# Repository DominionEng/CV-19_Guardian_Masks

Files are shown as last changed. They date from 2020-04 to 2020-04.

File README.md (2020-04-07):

# Description

In response to shortages in NIOSH-approved PPE during the COVID-19 crisis, many individuals including healthcare professionals and first responders are turning to improvised masks for protection. To help provide for more controlled protection under these circumstances, Dominion Engineering, Inc. (DEI) has developed a custom adaptor that, along with commonly available materials, can be used to convert a standard snorkel mask into a reusable, full face respirator that effectively protects the eyes, nose and mouth from airborne particles.  We have coordinated independent testing to confirm that these converted masks pass a standard mask fit test and to assess the efficacy of commonly available filter insert materials.

To assist individuals who may lack access to approved PPE such as N95 respirators and face shields, DEI is publishing the CV-19 Guardian Respirator Adaptor design here, along with instructions for making a converted mask using this adaptor.  For additional technical information, including filter efficacy testing results for commonly available materials that can be used to make filter inserts for this adaptor, refer to the attached PDF file.

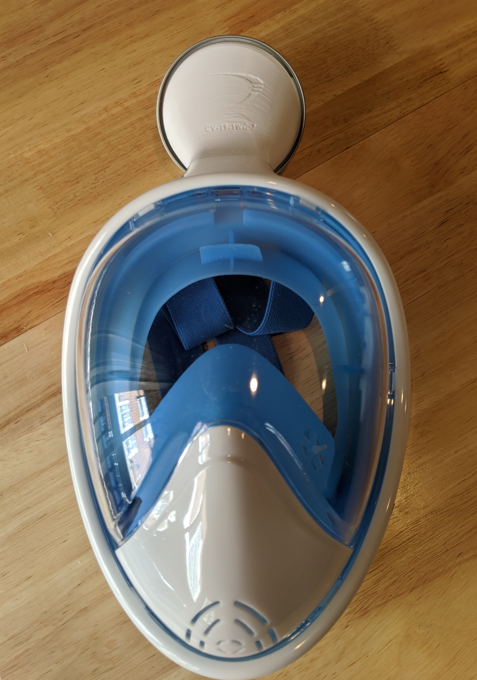
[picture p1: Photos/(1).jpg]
Mask with Adapter


**Disclaimer**: _Improvised devices of the type discussed herein are not NIOSH-approved and the user bears all liability associated with the use of such devices.  DEI is making this information available as a public service, but does not make any warranty, expressed or implied, that the use of the device described herein will protect a party from COVID-19 or any other airborne viruses._

**To assemble a converted respirator mask, you will need the following:**

1. 3D printed adaptor (design file attached)
2. Compatible snorkel mask
3. Filter insert material
4. Wide mouth lid (mason jar, or equivalent)

## Snorkel Mask

The CV-19 Guardian Respiratory Adaptor is designed to fit the [DIVELUX snorkel mask](https://www.amazon.com/dp/B072KDWVSV/ref=cm_sw_em_r_mt_dp_U_PJ5FEbJPZE8VG).  Many other commonly available snorkel masks utilize similar construction.  DEI will continue to evaluate the compatibility of other masks with the CV-19 Guardian Respirator Adaptor and publish additional compatibility information as it becomes available.

## Filter Insert

Once the CV-19 Guardian Respirator Adaptor is inserted into the compatible snorkel mask, a filter insert cut from a commonly available material that effectively captures airborne particles is placed on the sealing surface of the adaptor and secured in place using a compatible lid.  The attached PDF file provides instructions for properly making and using filter inserts, along with URL links for commonly available materials that provide effective protection against airborne particles.  One example material with good breathability and >99% filtration efficiency of airborne particles of interest is two layers of [ADO Pro Pac fabric](https://www.homedepot.com/p/ADO-Products-10-2-ft-x-375-ft-Pro-Pac-Insulation-Fabric-ICPP122/302709283), which is commonly used to capture particulate from blown insulation.

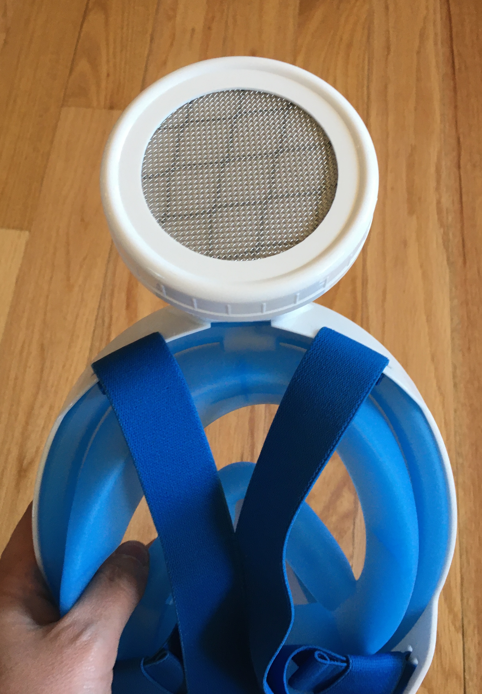
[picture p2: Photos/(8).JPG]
Filter Insert


As configured, most standard snorkel masks such as the DIVELUX mask allow the wearer breathe filtered air in through the CV-19 Guardian Respirator and filter insert, and exhale unfiltered air through a vent valve in the front of the mask.  This is equivalent to an N95 mask with an exhaust valve, which protects only the person wearing the mask, but not those in close proximity from any airborne particles expelled by the wearer.  Most full face coverage respirator masks utilize this type of construction because it is easier to breathe and prevents mask fogging and filter deterioration due to moisture.  However, if it is desirable for the mask to function in a similar manner to an N95 max without an exhaust valve, the vent valve in the snorkel mask can be effectively blocked by taping over it on the interior of the mask.  This makes it more difficult for the wearer to breathe through the mask, but ensures both inhaled and exhaled air are filtered (protecting both the wearer from surrounding airborne particles, as well as those in close proximity from any airborne particles expelled by the wearer).

## Wide Mouth Lid

For maximum compatibility and ease of use for the general public, the diameter and threading of the CV-19 Guardian Respirator Adaptor is the same as that of a wide mouth mason jar.  Any standard wide mouth mason jar lid ring (for canning) will fit the adaptor and function as intended (see photos).  Compatible lids with sprouting or straining inserts provide good structural protection for the filter insert.  One example lid of this type is the 
[Original Speed Strainer Lid® (wide mouth size)](https://www.unboundfarm.com/The-Original-Speed-Strainer-Lid®_p_12.html).

It is not recommended to cut a hole in a single-piece mason jar lid as the sharp edges could damage and compromise the integrity the filter insert.

## Details

For additional technical details, refer to the Photos and PDF file.

## 3D Print settings

* Printer used for prototyping: Prusa Mk3
* Rafts: No
* Supports: None
* Resolution: 0.2 mm
* Infill: 20%
* Filament: Hatchbox PLA, White

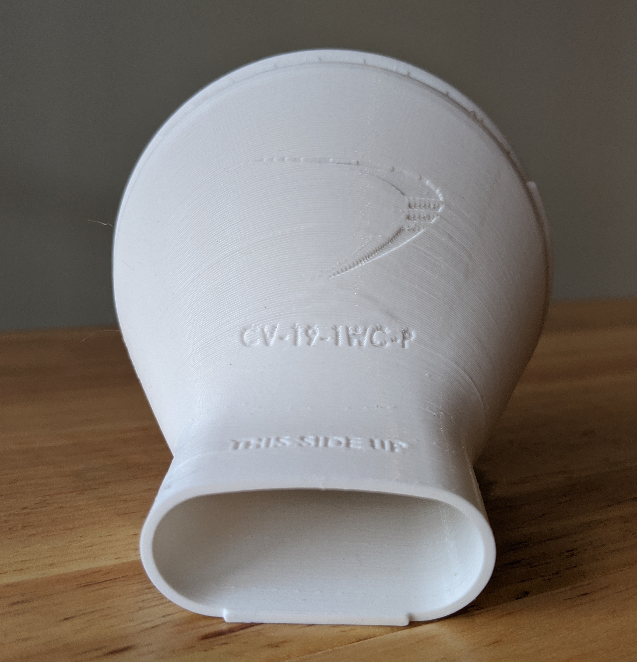
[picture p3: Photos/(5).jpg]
Adapter


## Material of construction and finishing options

* PETG or PLA are suitable.  In absence of these, other materials should be acceptable as well.
* ABS tends to shrink after production; a prototype made from this works acceptably, but the shrinkage could result in an inferior seal at the interface or require adjustment.
* PETG is chemically resistant, so it may be a good candidate if masks will be chemically decontaminated.
*  Multi-Jet Fusion (MJF) is expected to be an ideal process for commercial production of this part due to the durability of the resulting parts and demonstrated ability to withstand autoclave disinfection.

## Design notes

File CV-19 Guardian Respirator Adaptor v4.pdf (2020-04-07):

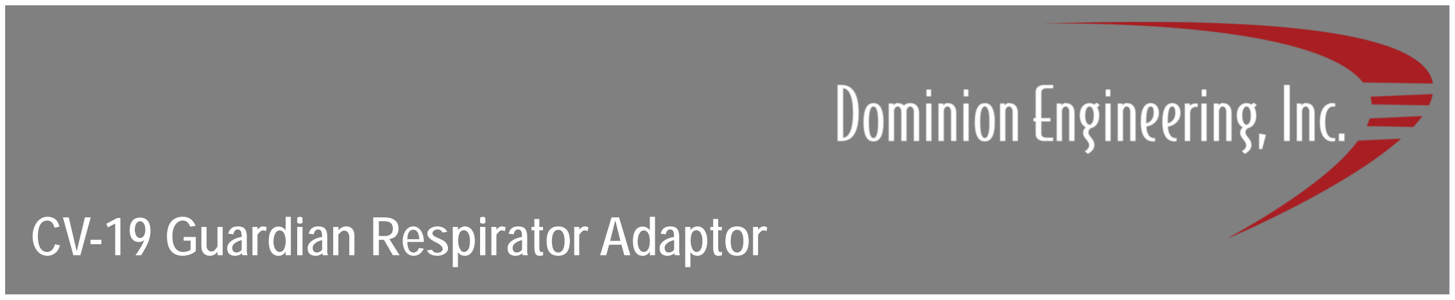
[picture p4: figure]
CV-19 Guardian Respirator Adaptor

Description
The CDC provides guidance for optimizing the supply of N95 respirators during the COVID-19 crisis (see Reference [1]). This includes crisis/alternate strategies such as the use of non-NIOSH approved masks when N95 respirators are no longer available. Along with compatible mask and filter insert, the CV-19 adaptor is designed to provide engineered protection in lieu of a homemade mask under these circumstances. To assist individuals who lack access to PPE, DEI has made this adaptor design freely available to the public and has separately published information regarding compatible masks and filter efficacy for commonly available materials (fabrics, HVAC filters, etc.). This device is not NIOSHapproved. User bears all liability associated with its use. DEI is making this information available as a public service, but does not make any warranty, expressed or implied, that the use of this device will protect a party from COVID-19 or any other airborne viruses.

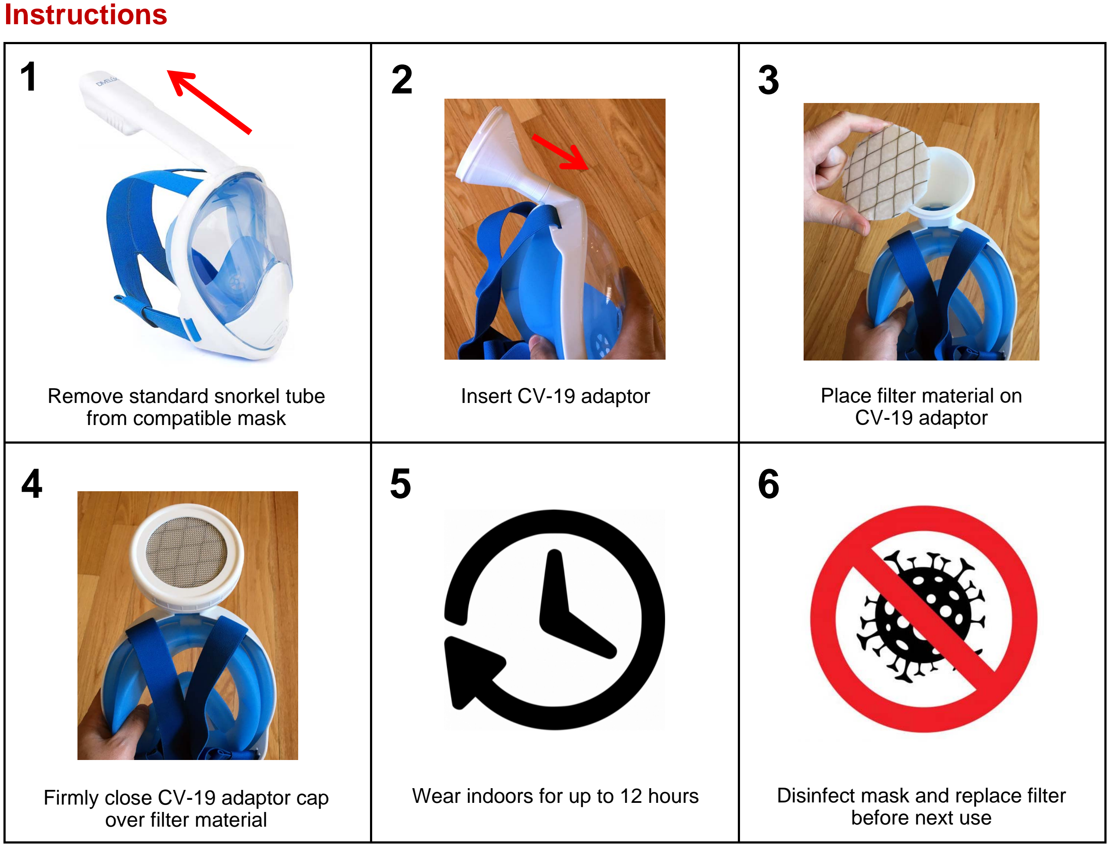
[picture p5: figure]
Instructions

1. https://www.cdc.gov/coronavirus/2019-ncov/hcp/respirators-strategy/crisis-alternate-strategies.html
1 Remove standard snorkel tube from compatible mask | 2 Insert CV-19 adaptor | 3 Place filter material on CV-19 adaptor
4 Firmly close CV-19 adaptor cap over filter material | 5 Wear indoors for up to 12 hours | 6 Disinfect mask and replace filter before next use

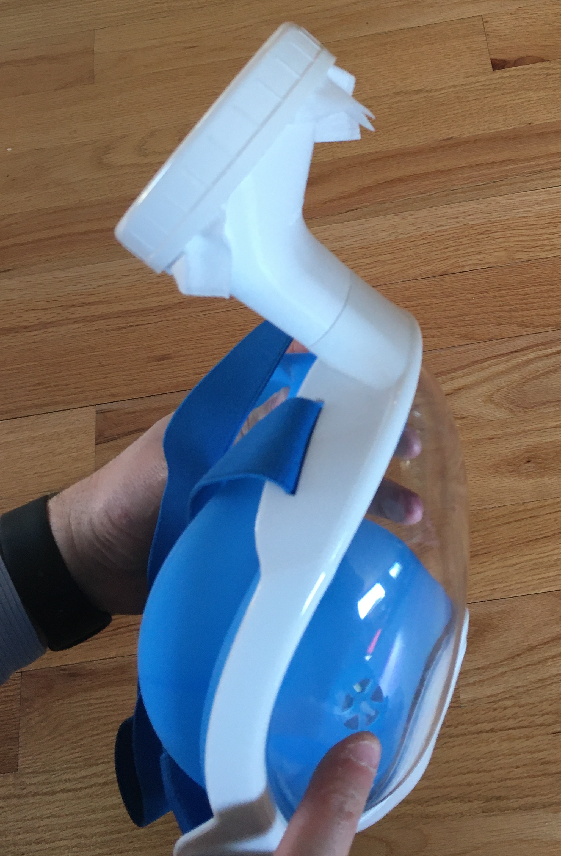
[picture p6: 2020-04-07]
Photos/(13)a.JPG

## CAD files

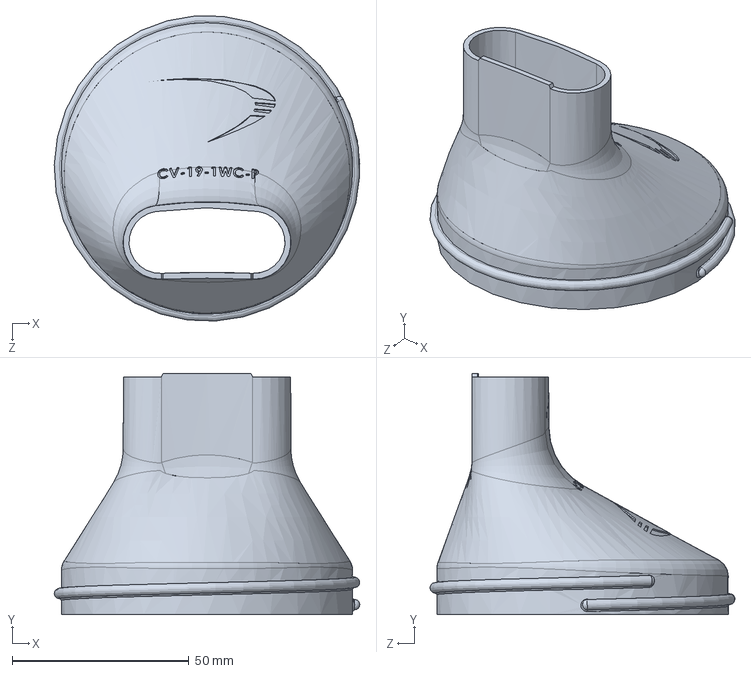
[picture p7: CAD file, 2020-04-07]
Solid Models/CV-19-1WC-P_V02.SLDPRT
86.6 x 68.3 x 86.4 mm

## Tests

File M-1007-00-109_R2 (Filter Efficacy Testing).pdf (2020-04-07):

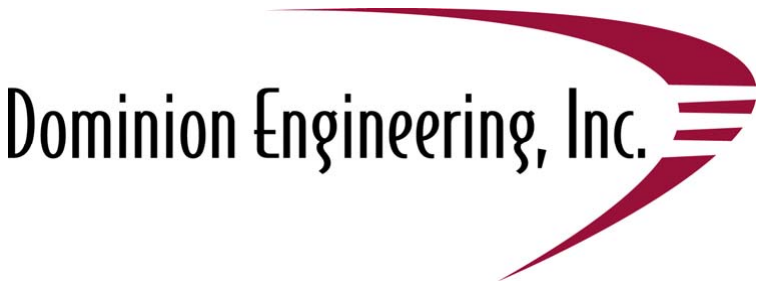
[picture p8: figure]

## MEMO

No.: | M-1007-00-109, Rev. 2
Date: | April 7, 2020
Subject: CV-19 Guardian Respirator Adaptor – Filter Insert Testing

### 1 Background

In response to the shortage of approved PPE such as N95 respirators and faceshields during the COVID-19 crisis, DEI developed the CV-19 Guardian Respirator Adaptor that, along with commonly available materials, can be used to convert a standard snorkel mask into a reusable, full face respirator that effectively protects the eyes, nose and mouth from airborne particles. In an emergency, commonly available materials such as HVAC filters and fabrics/netting for blown insulation can be cut into consumable filter inserts for use with the CV-19 Guardian Respirator Adaptor and a compatible mask as shown in Figure 1 and Figure 2.

DEI conducted testing to evaluate the efficacy of various materials that are readily available and can be used to make these filter inserts. This testing is summarized below.

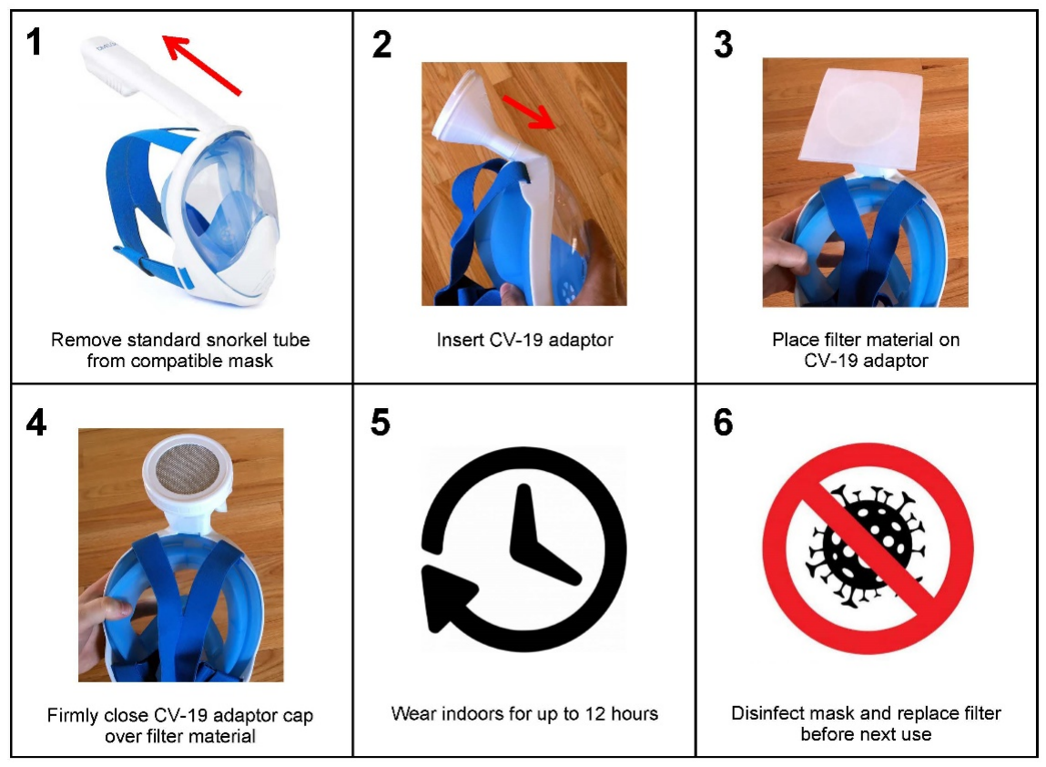
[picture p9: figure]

Figure 1 Use of Flexible Filter Insert in CV-19 Guardian Respirator Adaptor (ex., 2 layers of ADO Pro Pac insulation fabric)

M-1007-00-109, Rev. 2
p. 2 of 3

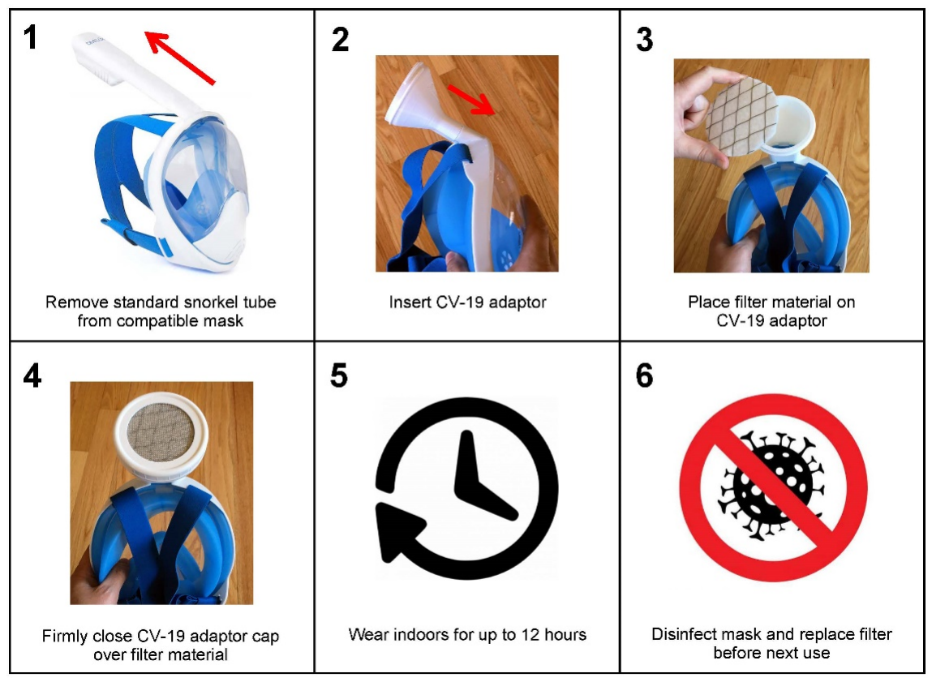
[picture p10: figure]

Figure 2 Use of Rigid Filter Insert in CV-19 Guardian Respirator Adaptor (ex., Aprilaire 213 furnace filter with rigid metal backing)

### 2 Filter Efficacy Testing

A converted respirator mask assembled using a DIVELUX mask, a CV-19 Guardian Respirator Adaptor and filter insert were subjected to and successfully passed a standard mask fit test using a PortaCount 8038 testing system as shown in Figure 3.

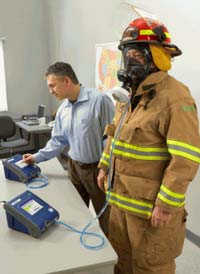
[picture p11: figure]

Figure 3 Respirator Fit Testing Using PortaCount 8038

M-1007-00-109, Rev. 2
p. 3 of 3
This testing system was also used to test the filtration efficiency of a number of readily available materials that could be used to make consumable filter inserts for the CV-19 Guardian Respirator Adaptor. In these tests, airborne particles were passed through candidate filter inserts and the particle concentration was measured before and after passing through the filter insert. Test results are summarized in Table 1.

As summarized in this table, a number of commonly available materials were found to capture >99% of airborne particles of interest*
with good breathability. When paired with a suitably tight fitting mask, filter inserts made from these materials provide a level of protection equivalent to or exceeding that of an N95 respirator (>95% capture, including leakage). In testing presented herein, a DIVELUX snorkel mask fitted with a CV-19 Guardian Respirator Adaptor and such filter inserts met the filtration performance requirements for an N95 respirator under typical fit testing activities (talking, moving head, bending over, etc.).

When making and installing filter inserts from flexible material such as the ADO Pro Pac insulation fabric, it is recommended that the chosen material be cut into squares at least 4.5 x 4.5 inches in size (see Figure 1). This ensures that the filter insert completely covers the sealing face of the adaptor and is held in place between the threads of the adaptor and lid. The four corners of the square should stick out past the lid after assembly in equal amounts, indicating that the full sealing face of the adapter is covered with material. Use of flexible sheet material as described above is the recommended approach in most cases, as it requires the least precision and is easily done without special tools.

When making and installing filter inserts from rigid material such as the Aprilair 213 furnace filter which has a robust metal backing, the filter insert must be cut into a circle with a diameter of 3.40 inches and pressed into the lid with the metal grid oriented away from the adaptor (see Figure 2). This ensures that the filter media seals properly against the adaptor, and that the filter insert is reliably positioned.

*
The test equipment used counts particles that are in the 0.02 to 1.0 micron size range.

M-1007-00-109, Rev. 2
p. 4 of 3
Table 1 | Filtration Efficiency of Commonly Available Materials
Description | Ambient Particulate | Filtered Particulate | Filter Efficiency (% Capture) | Recommended as Filter Insert? | Comments & Product URL
ADO Pro Pac Insulation Fabric (2 layers) | 801 | 5 | 99.4% | Yes | Excellent filtration, good breathability, readily available in large quantities, easy to work with
https://www.homedepot.com/p/ADO-Products-10-2-ft-x-375-ft-Pro-Pac-Insulation-Fabric-ICPP122/302709283
ADO Pro Pac Insulation Fabric (1 layer) | 807 | 39 | 95.2% | Yes (2 layers) | Acceptable, but recommend using 2 layers for improved filtration https://www.homedepot.com/p/ADO-Products-10-2-ft-x-375-ft-Pro-Pac-Insulation-Fabric- ICPP122/302709283
Aprilaire 213 Furnace Filter | 102 | 0.01 | 100.0% | Yes | Excellent filtration, good breathability, includes helpful metal reinforcement https://www.amazon.com/dp/B00R3G53NI/ref=cm_sw_em_r_mt_dp_U_NwcGEb2XZH3ZD
Filtrete 1000 Alergen Defense AC Filter | 100 | 0.1 | 99.9% | Yes | Excellent filtration, good breathability, but small pleats and metal grids are hard to work with https://www.amazon.com/dp/B004Q69HIU/ref=cm_sw_em_r_mt_dp_U_8S-GEb6YMVXM5
Vigoro Landscape Fabric Weed Barrier | 809 | 39 | 95.2% | No | May work acceptably with 2 layers (similar to ADO Pro Pac insulation fabric); not yet tested
https://www.homedepot.com/p/Vigoro-4-ft-x-200-ft-Polypropylene-Landscape-Fabric-Weed-Barrier-2232RV/311040972
Swiffer Dry Sweeping Cloth (4 layers) | 129 | 0.2 | 99.8% | No | Useful for sewn DIY masks in low quantities
Swiffer Dry Sweeping Cloth (1 layer) | 72 | 6 | 91.7% | No
Vigoro Matrix Grid Landscape Fabric | 807 | 210 | 74.0% | No | https://www.homedepot.com/p/Vigoro-4-ft-x-100-ft-Matrix-Grid-Landscape-Fabric- VPNM410085/302802172
Brown Cone Coffee Filter | 113 | 20 | 82.3% | No
Cotton Round Pads (for Makeup Removal) | 112 | 12 | 89.3% | No
Hanes Cotton T-Shirt (2 layers) | 110 | 22 | 80.0% | No | Included for reference, poor overall performance
